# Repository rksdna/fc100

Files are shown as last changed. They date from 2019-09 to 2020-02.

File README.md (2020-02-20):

# fc100

Two channel reciprocal frequency counter / interval timer with analog interpolators.

Structure:

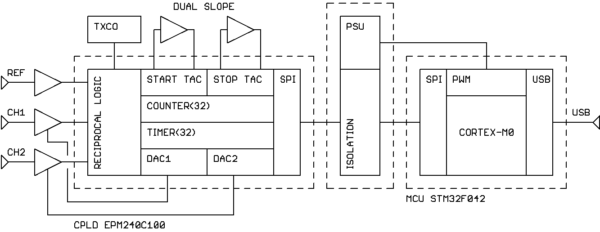
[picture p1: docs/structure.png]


Modes of operation:

- frequency / period measurement, up to 100MHz without prescaler
- time interval measurement (1nS resolution, with interpolators) with independent selection of start and end events (any edge, any input) 
- event counting
- gated frequency / period measurement

Hardware features:

- USB connection as CDC device class
- frontend galvanic isolation
- standard 1 MΩ / 10 pF inputs for 10:1 oscilliscope probes (±5 threshold range, 20 mV sensitivity)
- external connected or built-in 10 MHz reference (TCXO)

Hardware image:

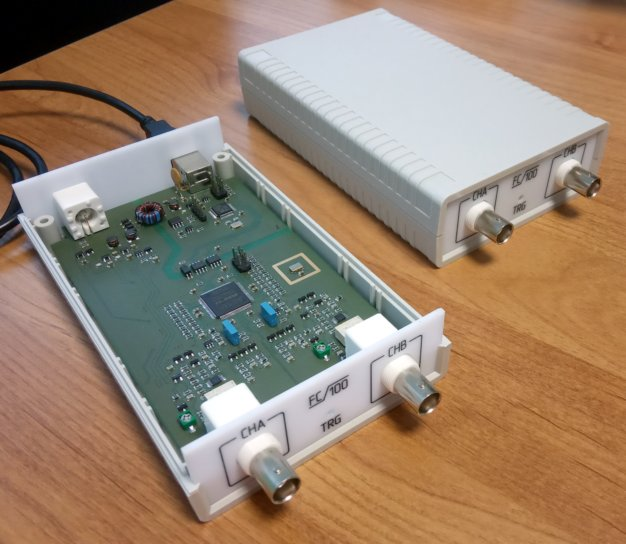
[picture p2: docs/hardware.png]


Software features:

- basic statistic and post-processing
- Debian / Windows portable

Screenshots:

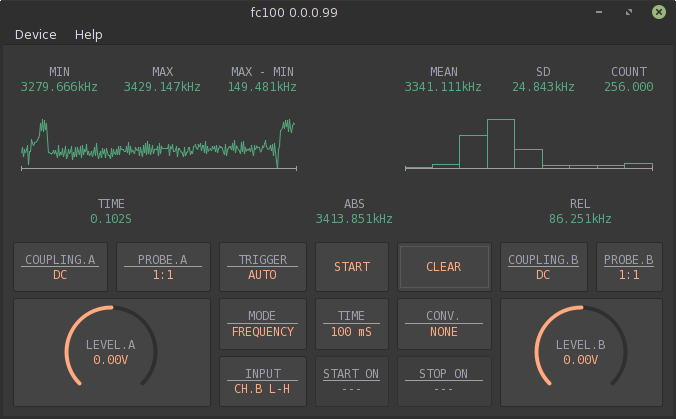
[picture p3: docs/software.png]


How to build:

- Debian `REPO_PATH/software/deploy/debian/deploy.sh PATH_TO_REPO/software OUTPUT_DEB_DIRECTORY`
- Windows `REPO_PATH/software/deploy/windows/deploy.sh PATH_TO_REPO/software OUTPUT_MSI_DIRECTORY` 

Cross-compile Qt for Windows: `REPO_PATH/software/deploy/windows/i686-w64-mingw32-qt-5.9.5.sh`

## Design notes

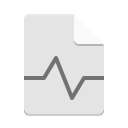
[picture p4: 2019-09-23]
software/arts/fc100_128.png

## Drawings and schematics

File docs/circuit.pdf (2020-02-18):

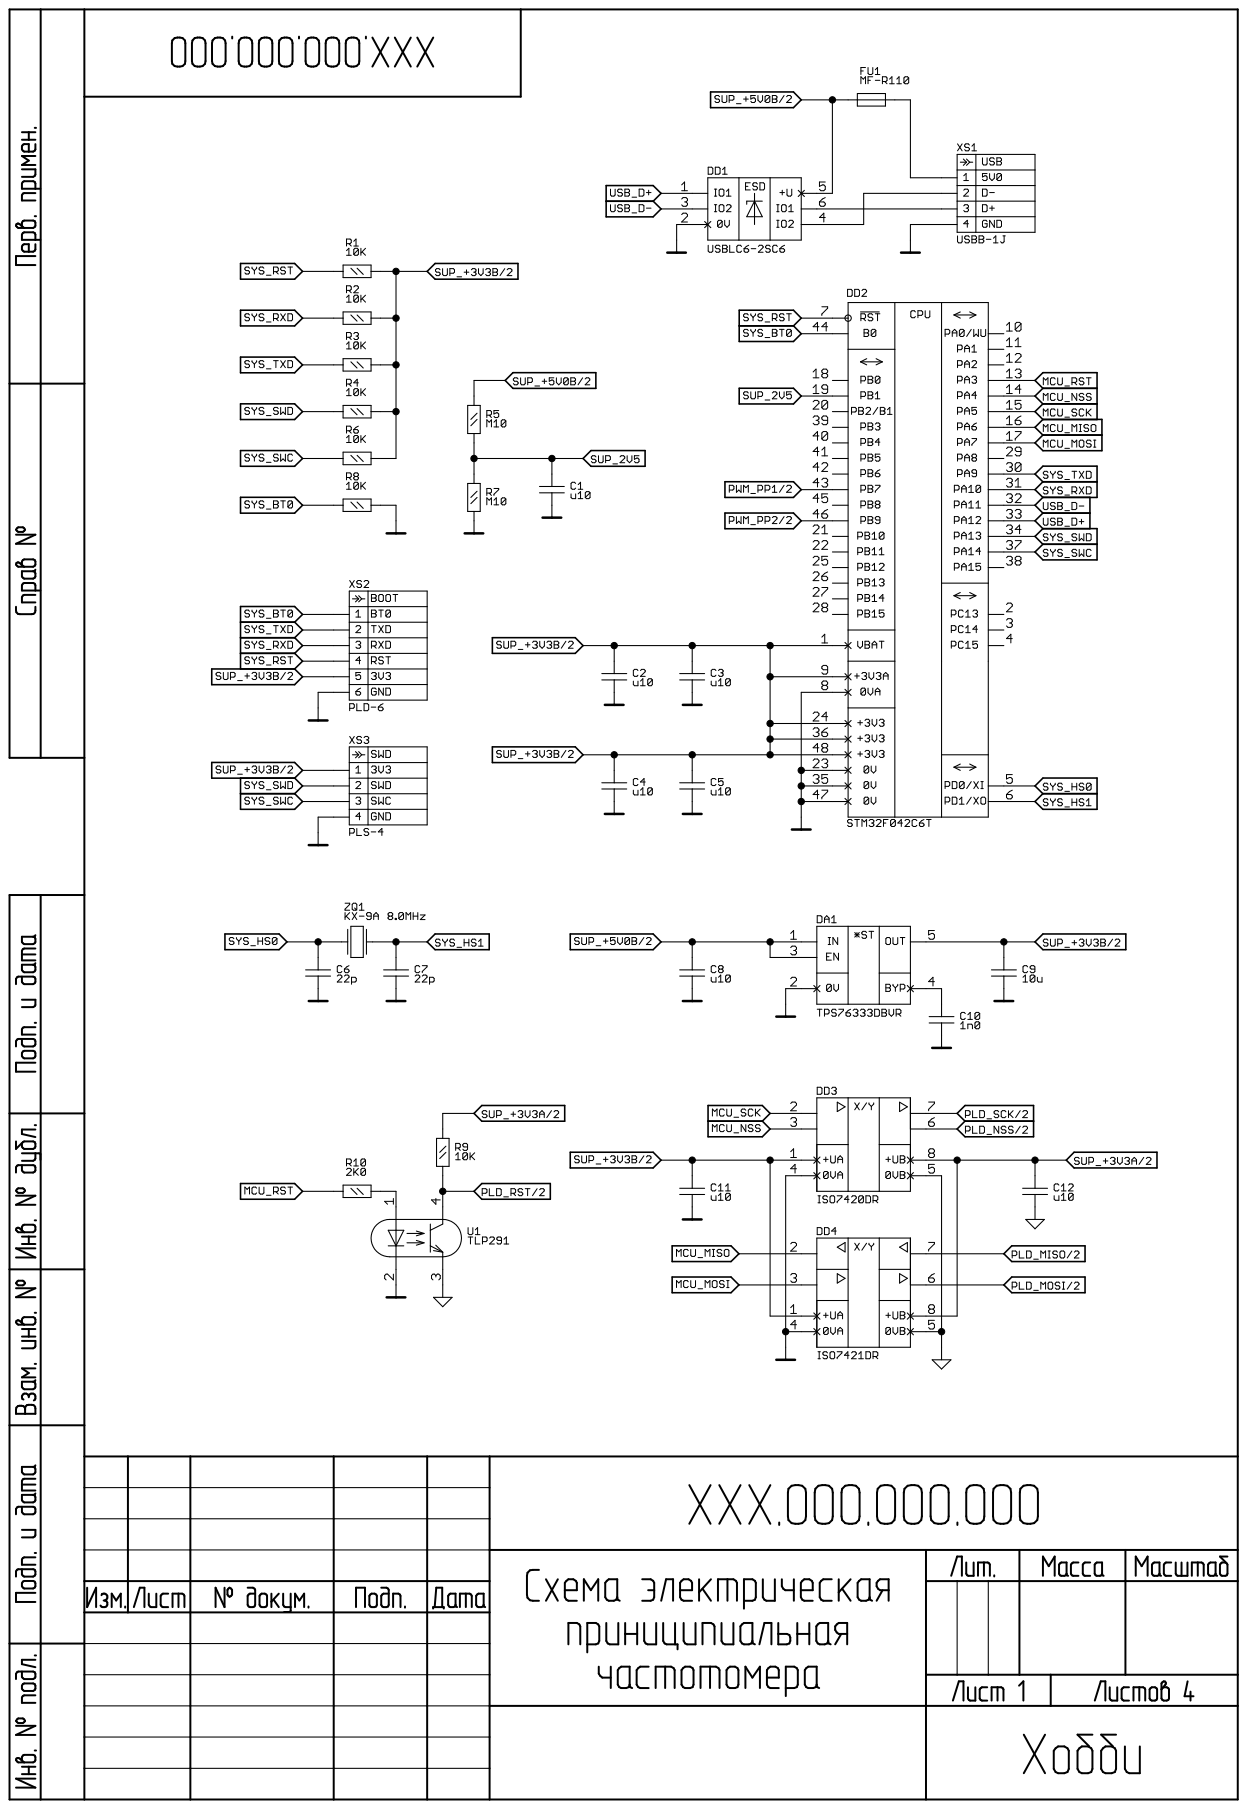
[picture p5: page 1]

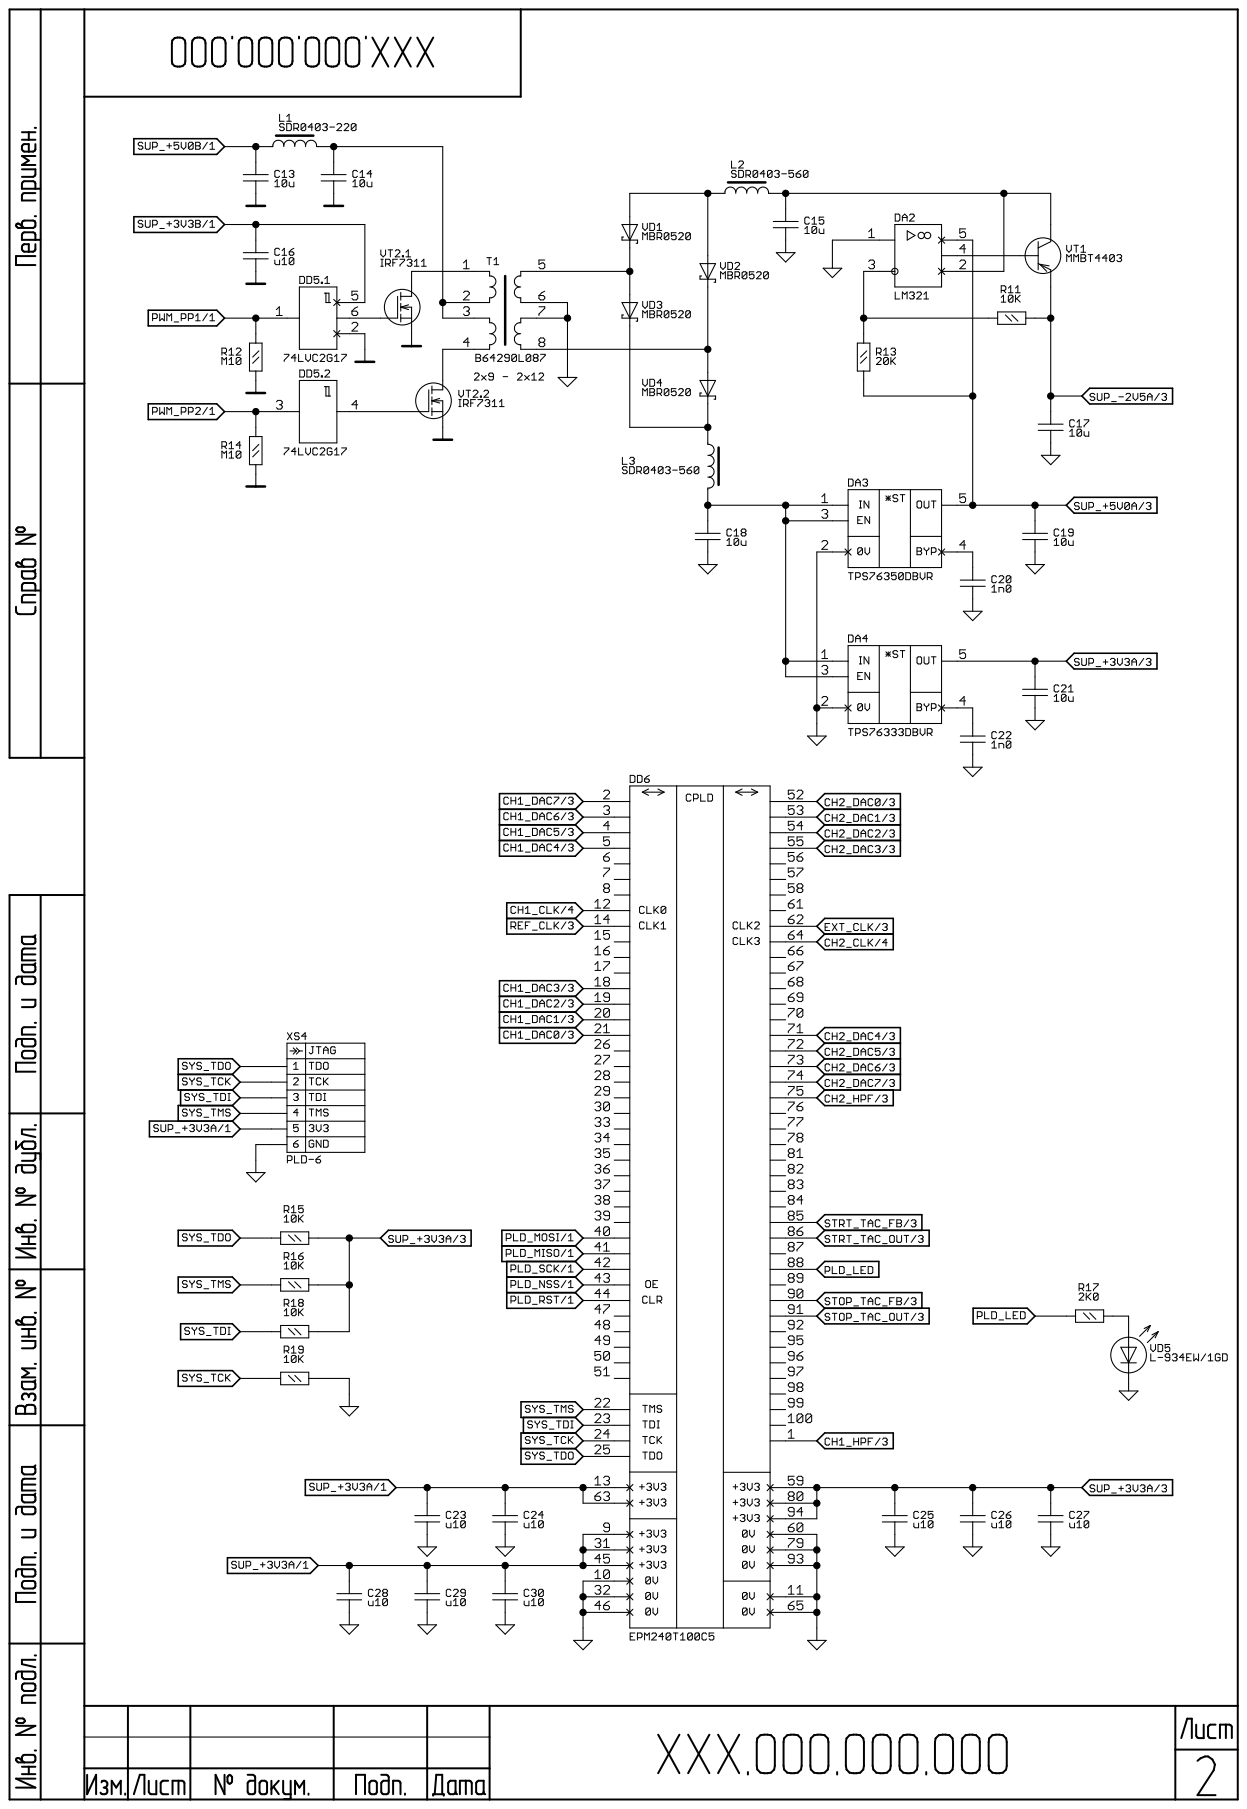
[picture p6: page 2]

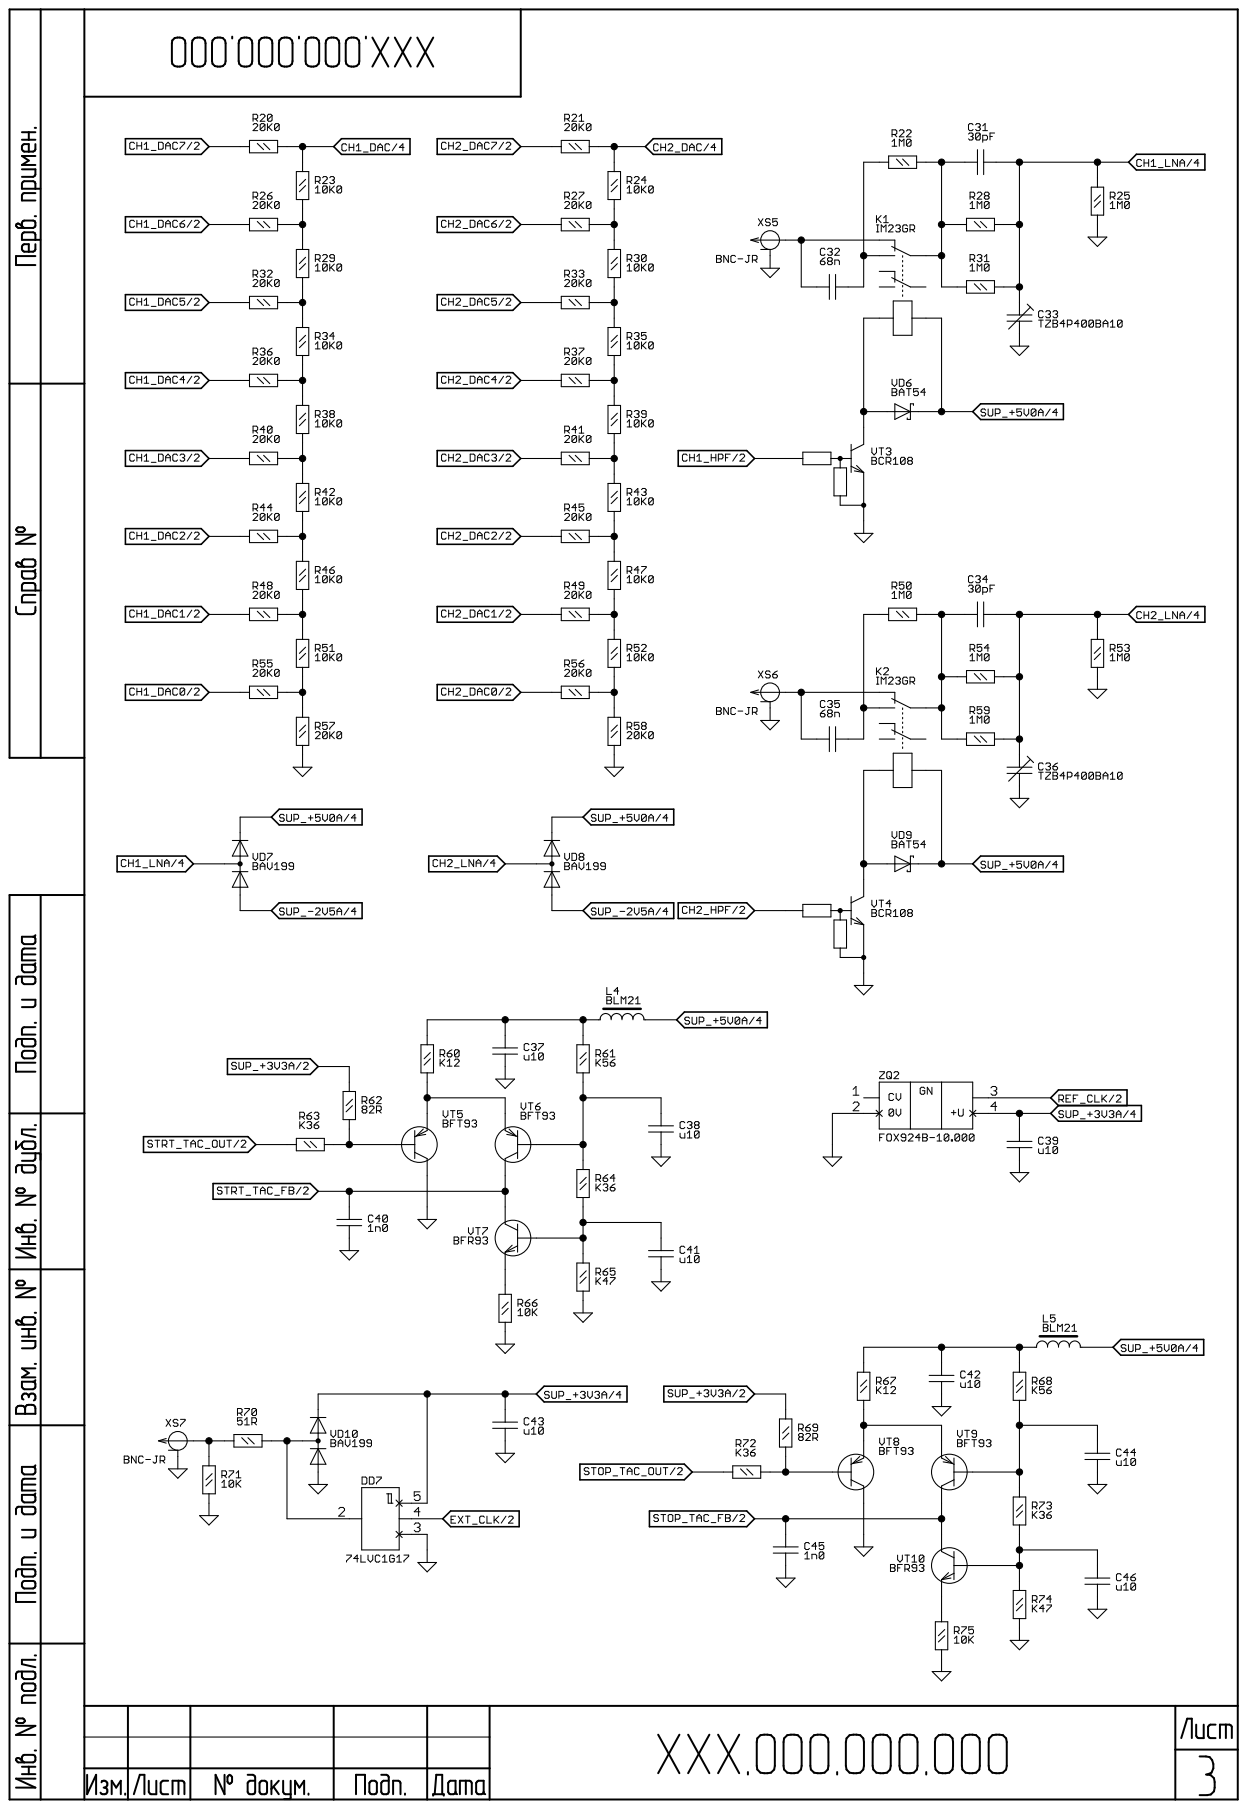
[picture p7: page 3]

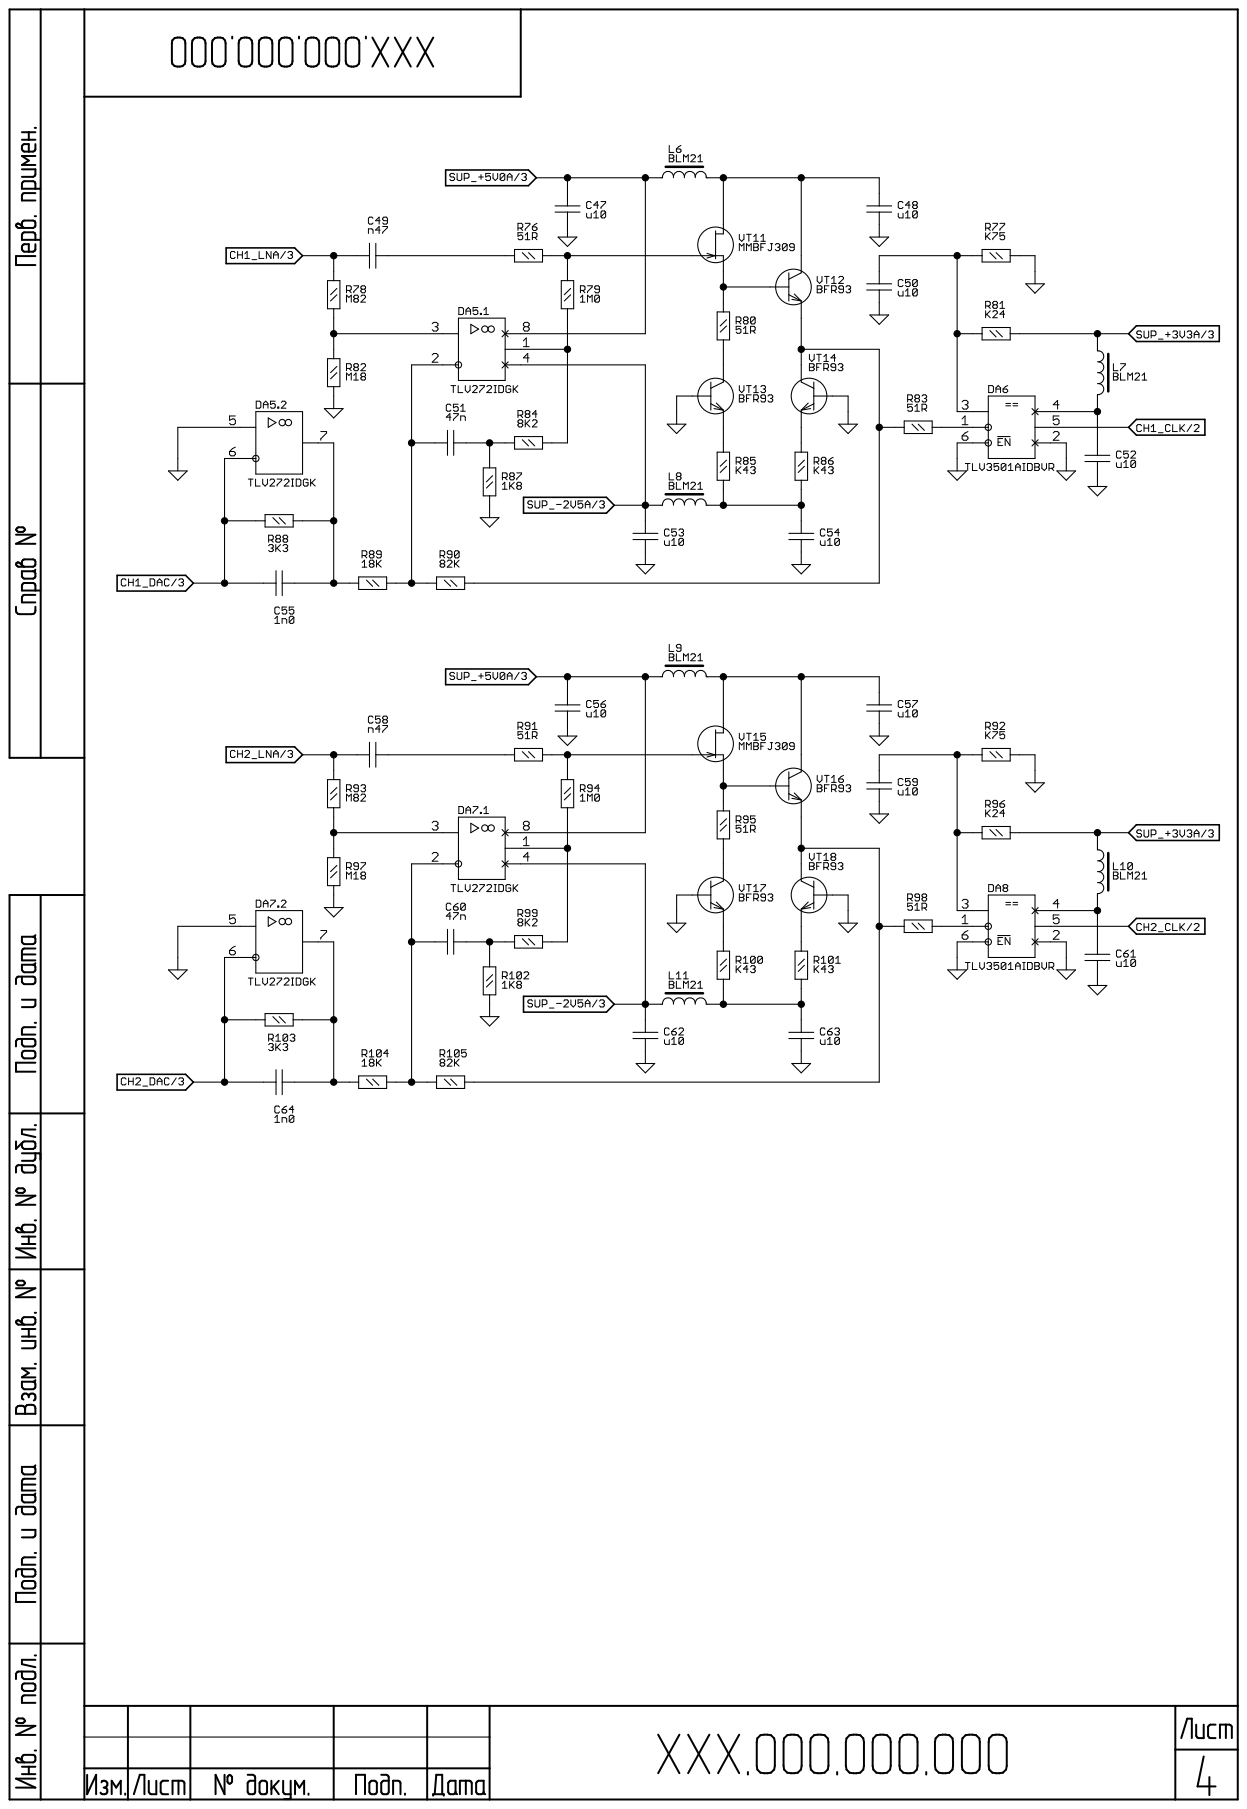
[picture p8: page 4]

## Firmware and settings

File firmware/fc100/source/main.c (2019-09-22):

/*
 * Reciprocal counter USB bridge
 * Copyright (c) 2018 rksdna, murych
 *
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
 * THE SOFTWARE IS PROVIDED "AS IS", WITHOUT WARRANTY OF ANY KIND, EXPRESS OR
 * IMPLIED, INCLUDING BUT NOT LIMITED TO THE WARRANTIES OF MERCHANTABILITY,
 * FITNESS FOR A PARTICULAR PURPOSE AND NONINFRINGEMENT. IN NO EVENT SHALL THE
 * AUTHORS OR COPYRIGHT HOLDERS BE LIABLE FOR ANY CLAIM, DAMAGES OR OTHER
 * LIABILITY, WHETHER IN AN ACTION OF CONTRACT, TORT OR OTHERWISE, ARISING FROM,
 * OUT OF OR IN CONNECTION WITH THE SOFTWARE OR THE USE OR OTHER DEALINGS IN
 * THE SOFTWARE.
 */

#include <threads.h>
#include <timers.h>
#include <debug.h>
#include <tools.h>
#include <cdc.h>
#include "counter.h"
#include "device.h"
#include "slip.h"

#define V_OFF 475
#define V_ON 485

enum state
{
    IDLE_STATE,
    START_TIME_STATE,
    START_FREQUENCY_STATE,
    START_DUTY_STATE,
    START_GATED_FREQUENCY_STATE,
    DUTY_1_STATE,
    DUTY_2_STATE,
    DUTY_3_STATE,
    BUSY_1_STATE,
    BUSY_2_STATE,
    BUSY_3_STATE,
    CALIBRATION_1_STATE,
    CALIBRATION_2_STATE
};

enum
{
    POLL_COMMAND,
    START_TIME_COMMAND,
    START_FREQUENCY_COMMAND,
    START_DUTY_COMMAND,
    START_GATED_FREQUENCY_COMMAND
};

enum
{
    FAIL_STATUS,
    DONE_STATUS,
    BUSY_STATUS
};

struct parameters
{
    u32_t command;
    u32_t duration;
    u8_t threshold1;
    u8_t threshold2;
    u8_t coupling1;
    u8_t coupling2;
    u8_t ref_source;
    u8_t start_event;
    u8_t stop_event;
    u8_t count_event;
};

struct variables
{
    u32_t status;
    u32_t counter1;
    u32_t timer1;
    u32_t counter2;
    u32_t timer2;
    u8_t tac_start1;
    u8_t tac_stop1;
    u8_t tac_start2;
    u8_t tac_stop2;
    u8_t fs_start;
    u8_t fs_stop;
    u8_t zs_start;
    u8_t zs_stop;
};

static struct parameters params;
static struct variables vars;
static u32_t duration;

static enum state control(enum state state, u32_t elapsed, struct counter *regs)
{
    switch (state)
    {
    case IDLE_STATE:
        regs->dac1 = 255 - params.threshold1;
        regs->dac2 = 255 - params.threshold2;
        regs->mode =
                COUNTER_MODE_TMR_BITS(params.ref_source) |
                COUNTER_MODE_CLR;
        regs->ctrl =
                COUNTER_CTRL_HPF_CH1_BITS(params.coupling1) |
                COUNTER_CTRL_HPF_CH2_BITS(params.coupling2) |
                COUNTER_CTRL_CLR;
        break;

    case START_TIME_STATE:
        duration = params.duration;
        regs->dac1 = 255 - params.threshold1;
        regs->dac2 = 255 - params.threshold2;

        regs->mode =
                COUNTER_MODE_STRT_BITS(params.start_event) |
                COUNTER_MODE_STOP_BITS(params.stop_event) |
                COUNTER_MODE_CNT_BITS(params.stop_event) |
                COUNTER_MODE_TMR_BITS(params.ref_source) |
                COUNTER_MODE_CLR;

        regs->ctrl =
                COUNTER_CTRL_HPF_CH1_BITS(params.coupling1) |
                COUNTER_CTRL_HPF_CH2_BITS(params.coupling2) |
                COUNTER_CTRL_STRT | COUNTER_CTRL_STOP;

        return BUSY_1_STATE;

    case START_FREQUENCY_STATE:
        duration = params.duration;
        regs->dac1 = 255 - params.threshold1;
        regs->dac2 = 255 - params.threshold2;

        regs->mode =
                COUNTER_MODE_STRT_BITS(params.count_event) |
                COUNTER_MODE_STOP_BITS(params.count_event) |
                COUNTER_MODE_CNT_BITS(params.count_event) |
                COUNTER_MODE_TMR_BITS(params.ref_source) |
                COUNTER_MODE_CLR;

        regs->ctrl =
                COUNTER_CTRL_HPF_CH1_BITS(params.coupling1) |
                COUNTER_CTRL_HPF_CH2_BITS(params.coupling2) |
                COUNTER_CTRL_STRT;

        return BUSY_1_STATE;

    case START_DUTY_STATE:
        duration = params.duration;
        regs->dac1 = 255 - params.threshold1;
        regs->dac2 = 255 - params.threshold2;

        regs->mode =
                COUNTER_MODE_STRT_BITS(params.count_event) |
                COUNTER_MODE_STOP_BITS(params.count_event) |
                COUNTER_MODE_CNT_BITS(params.count_event) |
                COUNTER_MODE_TMR_BITS(params.ref_source) |
                COUNTER_MODE_CLR;

        regs->ctrl =
                COUNTER_CTRL_HPF_CH1_BITS(params.coupling1) |
                COUNTER_CTRL_HPF_CH2_BITS(params.coupling2) |
                COUNTER_CTRL_STRT | COUNTER_CTRL_STOP;

        return DUTY_1_STATE;

    case START_GATED_FREQUENCY_STATE:
        duration = params.duration;
        regs->dac1 = 255 - params.threshold1;
        regs->dac2 = 255 - params.threshold2;

        regs->mode =
                COUNTER_MODE_STRT_BITS(params.start_event) |
                COUNTER_MODE_STOP_BITS(params.stop_event) |
                COUNTER_MODE_CNT_BITS(params.count_event) |
                COUNTER_MODE_TMR_BITS(params.ref_source) |
                COUNTER_MODE_CLR;

        regs->ctrl =
                COUNTER_CTRL_HPF_CH1_BITS(params.coupling1) |
                COUNTER_CTRL_HPF_CH2_BITS(params.coupling2) |
                COUNTER_CTRL_STRT | COUNTER_CTRL_STOP;

        return BUSY_1_STATE;

    case DUTY_1_STATE:
        regs->mode &= ~COUNTER_MODE_CLR;
        if (regs->ack & COUNTER_ACK_STRT)
        {
            regs->ctrl |= COUNTER_CTRL_TEST;
            return DUTY_2_STATE;
        }

        if (elapsed > duration)
        {
            vars.status = FAIL_STATUS;
            return IDLE_STATE;
        }

        break;

    case DUTY_2_STATE:
        if (regs->ack & COUNTER_ACK_STOP)
        {
            debug("aux measure %d, %d, %d, %d\n", regs->tac_strt, regs->tac_stop, regs->cnt, regs->tmr);
            vars.counter2 = regs->cnt;
            vars.timer2 = regs->tmr;
            vars.tac_start2 = regs->tac_strt;
            vars.tac_stop2 = regs->tac_stop;

            regs->mode ^= COUNTER_MODE_STOP_0 | COUNTER_MODE_CNT_0;
            regs->mode |= COUNTER_MODE_CLR;
            return BUSY_1_STATE;
        }

        if (elapsed > duration)
        {
            vars.status = FAIL_STATUS;
            return IDLE_STATE;
        }

        break;

    case BUSY_1_STATE:
        regs->mode &= ~COUNTER_MODE_CLR;
        if (regs->ack & COUNTER_ACK_STRT)
        {
            regs->ctrl |= COUNTER_CTRL_TEST;
            return BUSY_2_STATE;
        }

        if (elapsed > duration)
        {
            vars.status = FAIL_STATUS;
            return IDLE_STATE;
        }

        break;

    case BUSY_2_STATE:
        if (elapsed > duration)
        {
            regs->ctrl |= COUNTER_CTRL_STOP;
            return BUSY_3_STATE;
        }

        break;

    case BUSY_3_STATE:
        if (regs->ack & COUNTER_ACK_STOP)
        {
            debug("measure %d, %d, %d, %d\n", regs->tac_strt, regs->tac_stop, regs->cnt, regs->tmr);
            vars.counter1 = regs->cnt;
            vars.timer1 = regs->tmr;
            vars.tac_start1 = regs->tac_strt;
            vars.tac_stop1 = regs->tac_stop;

            regs->mode |= COUNTER_MODE_CLR;
            regs->ctrl &= ~(COUNTER_CTRL_STRT | COUNTER_CTRL_STOP);
            regs->ctrl |= COUNTER_CTRL_CLB_FS;
            return CALIBRATION_1_STATE;
        }

        if (elapsed > duration)
        {
            vars.status = FAIL_STATUS;
            return IDLE_STATE;
        }

        break;

    case CALIBRATION_1_STATE:
        regs->mode &= ~COUNTER_MODE_CLR;
        if (regs->ack & COUNTER_ACK_STOP)
        {
            debug("full scale %d, %d\n", regs->tac_strt, regs->tac_stop);
            vars.fs_start = regs->tac_strt;
            vars.fs_stop = regs->tac_stop;

            regs->mode |= COUNTER_MODE_CLR;
            regs->ctrl &= ~COUNTER_CTRL_CLB_FS;
            regs->ctrl |= COUNTER_CTRL_CLB_ZS;
            return CALIBRATION_2_STATE;
        }

        if (elapsed > 10)
        {
            vars.status = FAIL_STATUS;
            return IDLE_STATE;
        }

        break;

    case CALIBRATION_2_STATE:
        regs->mode &= ~COUNTER_MODE_CLR;
        if (regs->ack & COUNTER_ACK_STOP)
        {
            debug("zero scale %d, %d\n", regs->tac_strt, regs->tac_stop);
            vars.zs_start = regs->tac_strt;
            vars.zs_stop = regs->tac_stop;

            regs->mode |= COUNTER_MODE_CLR;
            regs->ctrl &= ~(COUNTER_CTRL_CLB_ZS | COUNTER_CTRL_TEST);

            vars.status = DONE_STATUS;
            return IDLE_STATE;
        }

        if (elapsed > 10)
        {
            vars.status = FAIL_STATUS;
            return IDLE_STATE;
        }

        break;

    default:
        return IDLE_STATE;
    }

    return state;
}

static void slip_socket_handler(struct slip_socket *socket, const void *data, u32_t size)
{
    if (size == sizeof(struct parameters))
    {
        copy(&params, data, sizeof(struct parameters));
        if (params.command != POLL_COMMAND)
            vars.status = BUSY_STATUS;

        send_slip_response(socket, &vars, sizeof(struct variables));
    }
}

static void slip_handler(void *arg)
{
    WASTE(arg);

    set_cdc_timeout(10);
    start_cdc_service();
    debug("usb started\n");
    debug("- supply: %2.dV\n", get_device_voltage());

    while (get_device_voltage() > V_OFF)
    {
        struct slip_socket socket;
        bind_slip_socket(&socket, slip_socket_handler, read_cdc_data, write_cdc_data);

        yield_thread((condition_t)has_cdc_connection, 0);
        debug("usb connected\n");
        while (has_cdc_connection())
            poll_slip_socket(&socket);

        debug("usb disconnected\n");
    }

    stop_cdc_service();
    debug("usb stopped\n");
    debug("- supply: %2.dV\n", get_device_voltage());
}

static enum state slip_command(enum state state)
{
    switch (params.command)
    {
    case START_TIME_COMMAND:
        debug("time started\n");
        state = START_TIME_STATE;
        break;

    case START_FREQUENCY_COMMAND:
        debug("frequency started\n");
        state = START_FREQUENCY_STATE;
        break;

    case START_DUTY_COMMAND:
        debug("duty started\n");
        state = START_DUTY_STATE;
        break;

    case START_GATED_FREQUENCY_COMMAND:
        debug("gate frequency started\n");
        state = START_GATED_FREQUENCY_STATE;
        break;

    default:
        break;
    }

    params.command = POLL_COMMAND;
    return state;
}

static void counter_handler(void *arg)
{
    WASTE(arg);

    struct timer tm;
    struct counter regs;
    enum state state = IDLE_STATE;

    startup_device_counter(250);
    start_timer(&tm, -1);
    debug("counter started\n");
    debug("- supply: %2.dV\n", get_device_voltage());

    while (get_device_voltage() > V_OFF)
    {
        const enum state next = control(slip_command(state), tm.ticks, &regs);
        if (next != state)
        {
            state = next;
            stop_timer(&tm);
            start_timer(&tm, -1);
        }

        write_device_counter(COUNTER_DAC1, &regs.dac1, 4);
        read_device_counter(COUNTER_ID, &regs.id, 12);
    }

    stop_timer(&tm);
    shutdown_device_counter();
    debug("counter stopped\n");
    debug("- supply: %2.dV\n", get_device_voltage());
}

void main(void)
{
    static struct thread slip_thread;
    static u8_t slip_stack[512];

    static struct thread counter_thread;
    static u8_t counter_stack[512];

    startup_device();
    while (get_device_voltage() < V_ON)
        continue;

    start_thread(&slip_thread, (function_t)slip_handler, 0, slip_stack, sizeof(slip_stack));
    start_thread(&counter_thread, (function_t)counter_handler, 0, counter_stack, sizeof(counter_stack));
    debug("threads started\n");
    debug("- supply: %2.dV\n", get_device_voltage());
}

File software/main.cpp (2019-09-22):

#include <QIcon>
#include <QDebug>
#include <QTranslator>
#include <QApplication>
#include <QLibraryInfo>
#include <QStandardPaths>
#include "MainWindow.h"

int main(int argc, char *argv[])
{
    qsrand(QDateTime::currentMSecsSinceEpoch());

    QApplication application(argc, argv);
    application.setApplicationName(DEPLOY_PRODUCT);
    application.setApplicationVersion(DEPLOY_VERSION);
    application.setApplicationDisplayName(QString("%1 %2").arg(DEPLOY_PRODUCT, DEPLOY_VERSION));

    QIcon icon;
    icon.addFile(":/arts/fc100_16");
    icon.addFile(":/arts/fc100_24");
    icon.addFile(":/arts/fc100_32");
    icon.addFile(":/arts/fc100_48");
    icon.addFile(":/arts/fc100_64");
    icon.addFile(":/arts/fc100_72");
    icon.addFile(":/arts/fc100_96");
    icon.addFile(":/arts/fc100_128");

    application.setWindowIcon(icon);

    const QString locale = QLocale::system().bcp47Name();

    QTranslator qtTranslator;
    qtTranslator.load(QString("qt_%1.qm").arg(locale), QLibraryInfo::location(QLibraryInfo::TranslationsPath));
    application.installTranslator(&qtTranslator);

    QTranslator qtBaseTranslator;
    qtBaseTranslator.load(QString("qtbase_%1.qm").arg(locale), QLibraryInfo::location(QLibraryInfo::TranslationsPath));
    application.installTranslator(&qtBaseTranslator);

    QTranslator appTranslator;
    appTranslator.load(QStandardPaths::locate(QStandardPaths::AppDataLocation, QString("fc100_%1.qm").arg(locale)));
    application.installTranslator(&appTranslator);

    MainWindow window;
    window.show();

    return application.exec();
}

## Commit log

2018-02-12 Interpolators created
    [fc.brd, fc.sch]
2018-02-17 USB added
    [fc.brd, fc.sch]
2018-02-18 usb supply
    [fc.brd, fc.sch]
2018-02-18 Hardware ready
    [fc.brd, fc.sch]
2018-03-18 Firmware changed
    [fc.brd]
2018-06-02 fc full started
    [fc.brd, fc.sch]
2018-06-12 Software changed
    [fc.brd, fc.sch]
2018-06-21 Device supply implemented
2018-10-21 Firmware ready
    [frame.brd]
2019-01-12 Device channels
2019-01-13 Hardware renamed
    [board.brd, board.sch]
2019-04-02 Test device
2019-09-22 Device ready
